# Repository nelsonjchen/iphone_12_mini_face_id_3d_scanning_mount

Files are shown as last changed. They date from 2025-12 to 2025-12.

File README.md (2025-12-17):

# iPhone 12 mini TrueDepth Periscopic Face ID 3D Scanning Mount

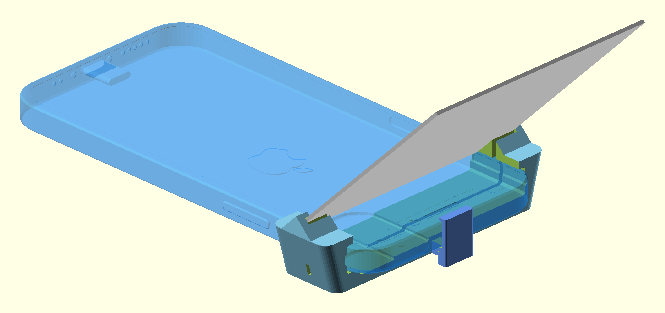
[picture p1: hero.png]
iPhone 12 Mini Face ID Mount Usage

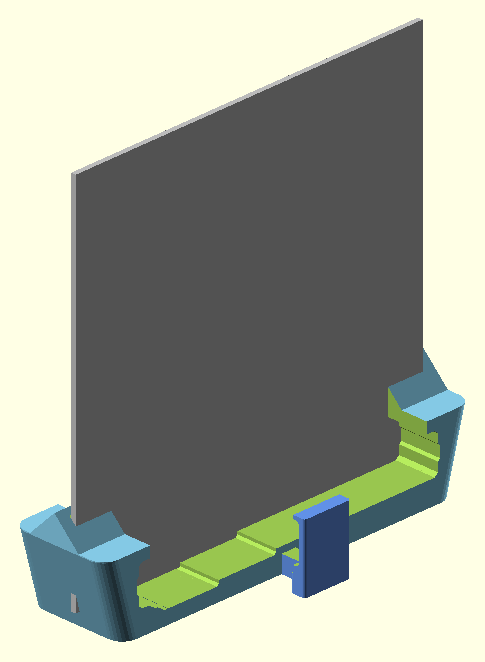
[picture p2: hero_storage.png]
iPhone 12 Mini Face ID Mount Storage


A 3D-printed mount to turn an iPhone 12 mini into a dedicated forward-facing Face ID scanner, designed for use with the [Heges 3D Scanner](https://hege.sh/) app. [EM3D Scanner App](https://em3dscanningapp.com/) might also be a good alternative too as it has a decent trial but I haven't tried it yet.

The iPhone 12 mini is an ideal candidate for this because it can often be found cheaply on the used market. Even units with battery damage, non-OEM screens, or cosmetic wear (like being "chewed on by a dog") are perfect, as long as the Face ID sensor is functional.

Real world though? Good for a snapshot or two after a bit. Large flat surfaces can show bends. But the sensors on the iPhone 12 mini seem to bug out. Not sure if it's due to my crap-condition iPhone 12 mini's battery bugging out and heating things to madness and so on. Don't be expecting to scan some engines or whatevers with this. Get a real scanner. This is for small things and poor budgets and/or drawer phones you might already have. 

## Features

*   **Precise Fit:** Designed specifically for the iPhone 12 Mini.
*   **Face ID Clearance:** Cutout ensures Face ID sensors (flood illuminator, dot projector) are unobstructed.
*   **Dual Modes:**
    *   **Usage Mode:** Holds the mirror at 45 degrees for scanning.
    *   **Storage Mode:** Vertical front slot to store the mirror flat with the base for compact transport.
*   **Non-Destructive:** No adhesive required on the phone.

## Hardware Needed

-   [3x3 Inch Square Mirrors (this kit has more than that too)](https://amzn.to/4rF7oln)
-   [iPhone 12 Mini (Amazon)](https://amzn.to/4aF0Vkh)
    - Of course, you can get it from other places like eBay.

## Ready to Print?

Use `./mount.stl` for printing.

Want to build it yourself? Follow the instructions below.

## Prerequisites

To build and modify this project, you will need:

-   [OpenSCAD](https://openscad.org/) (installed and in your PATH, or adjustable in the Makefile)
-   `make` (standard on macOS/Linux)

## Build Instructions

This project uses a `Makefile` to automate the generation of STL files and preview images.

1.  **Clone the repository:**
    ```bash
    git clone <repository-url>
    cd iphone_12_mini_face_id_mount
    ```

2.  **Build everything (STL and PNGs):**
    ```bash
    make
    ```

3.  **Build only the STL for printing:**
    ```bash
    make stl
    ```
    The output file will be `mount.stl`.

4.  **Clean up generated files:**
    ```bash
    make clean
    ```

## Printing Settings

-   **Layer Height**: 0.16mm Standard @BBL
-   **Variable Layer Height**: Enabled (Adaptive)
    -   When applying variable layer height, move the slider all the way to "Quality".

This should result in a snug fit for the iPhone 12 Mini and the mirror.

## File Structure

-   `mount.scad`: The core parametric design file.
-   `Makefile`: Build automation script.
-   `reference/`: Contains the reference STL for the iPhone 12 Mini.
-   `preview_*.png`: Generated preview images of the model.

## Inspirations

-   [Original Concept on Thingiverse](https://www.thingiverse.com/thing:3254381)

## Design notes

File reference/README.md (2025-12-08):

* iPhone 12 mini drawings from https://developer.apple.com/accessories/Accessory-Design-Guidelines.pdf
* iPhone 12 mini stl from https://www.thingiverse.com/thing:3254381

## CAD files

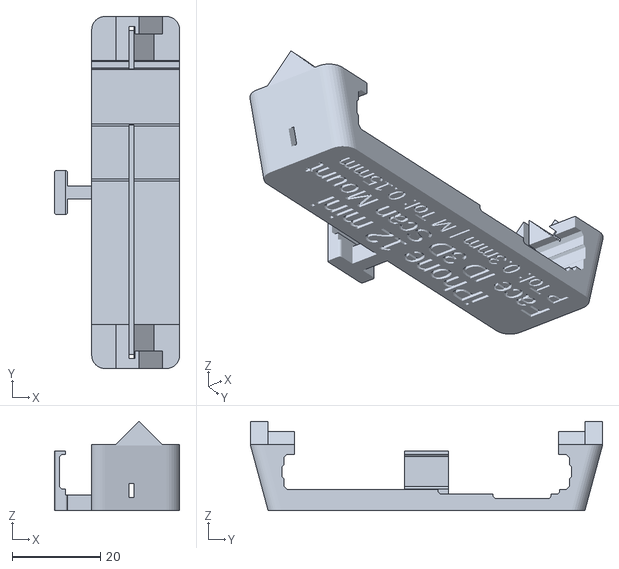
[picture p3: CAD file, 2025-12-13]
mount.stl
28.5 x 80.0 x 20.3

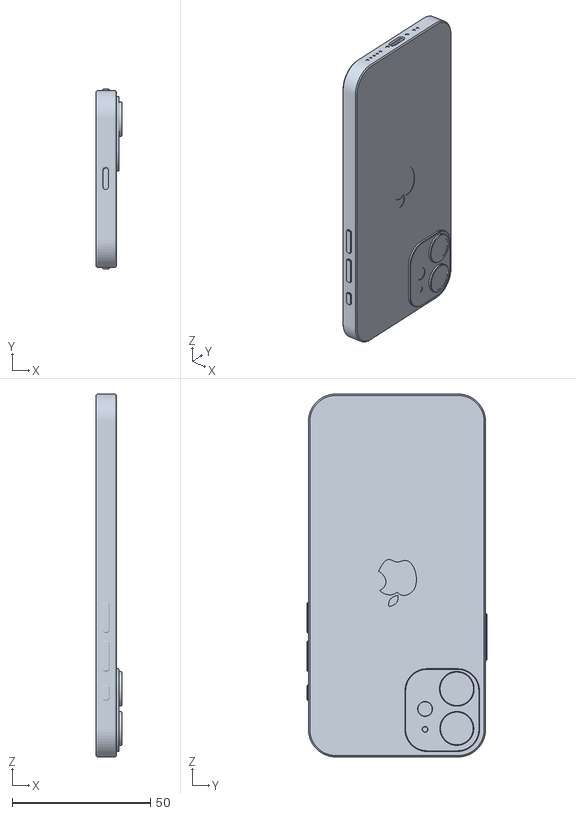
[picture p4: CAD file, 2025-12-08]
reference/iphone-12-mini.stl
9.40 x 65.2 x 131.5

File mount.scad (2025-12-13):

// =============================================================================
// iPhone 12 Mini Face ID 3D Scanning Mount
// =============================================================================

// -----------------------------------------------------------------------------
// 1. Configuration & Parameters
// -----------------------------------------------------------------------------

// -- Mirror Dimensions --
mirror_width = 75.2;
mirror_thickness = 1.0;
mirror_tolerance = 0.15;
mirror_length_tolerance = 0.5;

// -- Calculated Mirror Slot --
mirror_slot_thickness = mirror_thickness + mirror_tolerance;
mirror_slot_length = mirror_width + mirror_length_tolerance;
mirror_slot_width = mirror_width + mirror_tolerance;

// -- Storage Slot Configuration --
mirror_storage_depth = 12; // How deep the storage slot goes
mirror_storage_x_offset = -6; // X position of the vertical storage slot

// -- Mount Base Dimensions --
base_height = 15; // Thickness of the base block
base_top_z = 2.5; // Top surface of the base relative to origin
base_center_z = base_top_z - (base_height / 2);
base_shift_x = -5; // Shift base back for better support of phone
base_plate_thickness = 0.2; // Thickness of the hull plates (virtual)

// -- Mount Dimensions --
mount_corner_radius = 3;
mount_wall_thickness = 2.4;
mirror_housing_width = mirror_width + (2 * mount_wall_thickness);
mount_width = mirror_housing_width;
mount_taper_reduction = 8; // Total width reduction at bottom of base
mount_thickness = 20;
mount_angle = 45;

// -- Phone Fit & Alignment --
phone_fit_tolerance = 0.3;
guide_offset = 22; // Distance to the top of the phone guide
iphone_top_ref_x = -14; // Natural top of phone in reference STL at X = -14

// -- Cutouts --
face_id_cut_w = 30;
face_id_cut_h = 30;
face_id_cut_d = 60;

// -- Visualization Flags (Override via Command Line) --
show_phone_ref = true;
show_usage_mirror = true;
show_storage_mirror = true;

// -----------------------------------------------------------------------------
// 2. Helper Modules (Visuals & References)
// -----------------------------------------------------------------------------

module rounded_cube(size, r, center = true) {
  // Beveled/Rounded Box (Z-axis edges rounded)
  width = size[0];
  depth = size[1];
  height = size[2];

  tx = center ? -width / 2 : 0;
  ty = center ? -depth / 2 : 0;
  tz = center ? -height / 2 : 0;

  translate([tx, ty, tz]) {
    hull() {
      translate([r, r, 0]) cylinder(r=r, h=height, $fn=32);
      translate([width - r, r, 0]) cylinder(r=r, h=height, $fn=32);
      translate([width - r, depth - r, 0]) cylinder(r=r, h=height, $fn=32);
      translate([r, depth - r, 0]) cylinder(r=r, h=height, $fn=32);
    }
  }
}

module iphone_ref() {
  // Shifts the reference STL so the top of the phone matches guide_offset
  shift_x = -iphone_top_ref_x - guide_offset;

  translate([shift_x, 0, 0])
    rotate([0, 90, 0])
      import("reference/iphone-12-mini.stl");
}

// -- Visual Geometry --
module visual_references() {
  // iPhone 12 Mini Reference (Blue, transparent - Mockup)
  if (show_phone_ref) {
    color("DodgerBlue", 0.4)
      iphone_ref();
  }

  // Mirror Reference (Silver, visual only)

  if (show_usage_mirror) {
    %color("silver") {
      // Calculate visual position (same logic as cutout)
      z_offset_vis = (mirror_width + mirror_thickness) * sin(mount_angle) / 2;
      x_offset_vis = -(mirror_width - mirror_thickness) * sin(mount_angle) / 2;

      translate([x_offset_vis, 0, z_offset_vis])
        rotate([0, -mount_angle, 0])
          cube([mirror_thickness, mirror_width, mirror_width], center=true);
    }
  }

  // Storage Mirror Reference (Silver)
  if (show_storage_mirror) {
    %color("silver")
      translate([mirror_storage_x_offset, 0, base_top_z + (mirror_width / 2) - mirror_storage_depth])
        cube([mirror_thickness, mirror_width, mirror_width], center=true);
  }
}

// -----------------------------------------------------------------------------
// 3. Geometry Modules (Positive Shapes)
// -----------------------------------------------------------------------------

module taper_mask() {
  // Creates a volume that follows the base taper and extends upwards
  // Used to clip the mirror supports so they don't stick out
  mask_len = 50; // Long enough to cover the whole X range

  hull() {
    // Bottom Plate (Narrow)
    translate([base_shift_x, 0, base_top_z - base_height + (base_plate_thickness / 2)])
      rounded_cube([mask_len, mount_width - mount_taper_reduction, base_plate_thickness], r=mount_corner_radius, center=true);

    // Top Plate (Wide)
    translate([base_shift_x, 0, base_top_z - (base_plate_thickness / 2)])
      rounded_cube([mask_len, mount_width, base_plate_thickness], r=mount_corner_radius, center=true);

    // Sky Plate (Wide - extends up)
    translate([base_shift_x, 0, 50])
      rounded_cube([mask_len, mount_width, base_plate_thickness], r=mount_corner_radius, center=true);
  }
}

module mount_base() {
  color("skyblue") {
    union() {
      // Main Base Block
      // Extended back (-X) to support the shifted pillars
      // Tapered hull construction
      hull() {
        // Top plate (full width)
        translate([base_shift_x, 0, base_top_z - (base_plate_thickness / 2)])
          rounded_cube([mount_thickness, mount_width, base_plate_thickness], r=mount_corner_radius, center=true);

        // Bottom plate (tapered width)
        translate([base_shift_x, 0, base_top_z - base_height + (base_plate_thickness / 2)])
          rounded_cube([mount_thickness, mount_width - mount_taper_reduction, base_plate_thickness], r=mount_corner_radius, center=true);
      }

      // Angled Mirror Support (Top side)
      intersection() {
        taper_mask();
        rotate([0, -mount_angle, 0])
          translate([-2, 0, 5])
            cube([6, mirror_housing_width, 7], center=true);
      }

      // Angled Mirror Support (Bottom side - with cutout for lens clearance if needed)
      intersection() {
        taper_mask();
        difference() {
          rotate([0, -mount_angle, 0])
            translate([0, 0, 4])
              cube([5, mirror_housing_width, 9], center=true);
          rotate([0, -mount_angle, 0])
            translate([0, 0, 5])
              cube([5 + 1, mirror_housing_width - 8, 7 + 1], center=true);
        }
      }
    }
  }
}

module top_guide() {
  // Adds a guide/stop for the top of the phone

  spine_width = 10;
  // Calculate left edge of base from its definition in mount_base
  base_min_x = base_shift_x - (mount_thickness / 2);

  // Height Logic
  // Align bottom with base bottom
  base_bottom_z = base_top_z - base_height;
  g_top_z = 1; // Keep top flush with phone surface (Z=0)

  g_height = g_top_z - base_bottom_z;
  g_center_z = g_top_z - (g_height / 2);

  // Only draw if guide extends beyond base
  if (guide_offset > abs(base_min_x)) {
    color("cornflowerblue")
      union() {
        // 1. Central Spine (Flared)
        hull() {
          // Base connection (Wide)
          translate([(base_min_x) / 2, 0, g_center_z])
            rounded_cube([0.1, 1, g_height], r=1, center=true);

          // Guide connection (Standard Width)
          translate([( -guide_offset) / 2, 0, g_center_z])
            rounded_cube([0.1, 1, g_height], r=1, center=true);

          // Main body filler (optional, but ensures hull covers length)
          // Actually, just hulling the two ends (Base X and Guide X) works perfectly 
          // to create a linear taper.

          // Let's be precise:
          // At Base (left side)
          translate([base_min_x + 0.1, 0, g_center_z])
            rounded_cube([0.1, 1, g_height], r=1, center=true);

          // At Guide (right side - connection point)
          translate([-guide_offset + 1, 0, g_center_z])
            rounded_cube([0.1, 1, g_height], r=1, center=true);
        }

        // 2. Vertical Stop
        // Blocks the phone face
        translate([-guide_offset, 0, g_center_z])
          rounded_cube([3, spine_width, g_height], r=0.5, center=true);
      }
  }
}

// -----------------------------------------------------------------------------
// 4. Cutter Modules (Subtractive Shapes)
// -----------------------------------------------------------------------------

module mirror_cutout() {
  // Slot for the mirror
  z_offset = (mirror_slot_length + mirror_slot_thickness) * sin(mount_angle) / 2;
  x_offset = (mirror_slot_length - mirror_slot_thickness) * sin(mount_angle) / 2;

  translate([-x_offset, 0, z_offset])
    rotate([0, -mount_angle, 0])
      cube([mirror_slot_thickness, mirror_slot_width, mirror_slot_length], center=true);
}

module mirror_storage_slot() {
  // Vertical slot for storing the mirror
  // Extends from the bottom of the defined depth upwards to infinity (or 50mm)
  // to ensure the top is open/uncapped.
  slot_bottom_z = base_top_z - mirror_storage_depth;
  height = 50;
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

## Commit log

2025-12-08 feat: Add initial project files for iPhone 12 mini Face ID mirror mount, including documentation and reference STL.
    [iphone-12-mini.stl]
2025-12-08 feat: Add initial OpenSCAD design and build system for iPhone 12 mini Face ID mount, and update project instructions.
2025-12-08 feat: Implement initial OpenSCAD project structure for an iPhone 12 mini Face ID mount with build automation and preview generation.
2025-12-08 chore: remove generated stl files from git
2025-12-08 fix: adjust imported model rotation
    [mount.scad]
2025-12-08 feat: add iPhone profile cutout to mount and encapsulate iPhone reference in a module.
    [mount.scad]
2025-12-08 feat: Redesign mirror mount to use two pillars and a 45-degree slot for a 70mm mirror.
    [mount.scad]
2025-12-08 accurate mirror
    [mount.scad]
2025-12-08 feat: reduce mirror cutout tolerance and add angled mirror support
    [mount.scad]
2025-12-09 more tolerant
    [mount.scad]
2025-12-09 hold mirror better
    [mount.scad]
2025-12-09 refactor: remove unused `bottom_cleaner` module
    [mount.scad]
2025-12-09 feat: reduce length of upper angled mirror support
    [mount.scad]
2025-12-09 refactor: Rename mirror and slot dimension variables for clarity and consistency.
    [mount.scad]
2025-12-09 tweaks to tolerance
    [mount.scad]
2025-12-09 feat: add script to measure phone dimensions and refine phone positioning in mount.scad
    [mount.scad]
2025-12-09 tweaked spine
    [mount.scad]
2025-12-09 refactor: improve code organization with new section headers, add visual references, and enhance parameter and module documentation.
    [mount.scad]
2025-12-09 tweaked tolerance
    [mount.scad]
2025-12-09 feat: Adjust guide top Z-offset, vertical stop position, and notch clearing patch dimensions.
    [mount.scad]
2025-12-09 feat: Add tolerance values to the mount's text labels and adjust their vertical positioning.
    [mount.scad]
2025-12-09 mirror width
    [mount.scad]
2025-12-09 feat: Rework central spine to a flared, hulled design using rounded cubes and make the vertical stop rounded.
    [mount.scad]
2025-12-09 refactor: introduce variables for base shift, plate thickness, and taper reduction to improve configurability.
    [mount.scad]
2025-12-09 Adjust camera rotation for `preview_ortho.png` generation.
2025-12-09 docs: add hero image to README and clarify print settings
2025-12-09 revert to 75.2
    [mount.scad, mount.stl]
2025-12-13 storage mode
    [mount.scad, mount.stl]
